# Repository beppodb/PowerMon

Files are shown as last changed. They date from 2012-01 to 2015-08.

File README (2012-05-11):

PowerMon

PowerMon is a device that can be inserted between a computer power supply and the computer's main board to measure power usage at each of the DC power rails supplying the board. The device measures voltage and current on eight DC rails, reporting measurements at a rate of up to 1024 Hz per channel up to 3072 Hz aggregate, and fits in a standard 3.5" hard drive bay.

PowerMon has been used to resolve and highlight variations in power consumption and energy efficiency during individual sub-processes of software applications at the subsystem level.  The parts cost is about $150 each, in small batches. (Assembled cost ~$250, in quantities of 50.)

Related publications:
D. Bedard, M. Lim, R. Fowler, and A. Porterfield, \ldblquote PowerMon: Fine-Grained and Integrated Power Monitoring for Commodity Computer Systems,\rdblquote  Southeastcon, 2010. IEEE, pp start-finish, March 18-21, 2010.

The entire design is licensed under the Renci Open Source License v1.0 (see ./license), meaning, essentially, that you can use it in any otherwise legal project, as long as you provide attribution.

Directory tree:

+-application/    A sample application in C
| +-pm_app.c
+-assembly/       BOM, centroid, drawings, instructions
+-firmware/       Device firmware
| +-bootloader/
| +-system/
|   +-adm1191.c
|   +-adm1191.h
|   +-config.c
|   +-config.h
|   +-powermon.c
|   +-timer2.c
|   +-timer2.h
|   +-usart.c
|   +-usart.h
+-gerber/         Production drawings for printed circuit boards
+-pcb/            Board layout, in Eagle PCB, PDF formats
+-schematic/      Schematic, in Eagle PCB, PDF formats
+-README          This file.
+-license         The RENCI Open Source License v1.0

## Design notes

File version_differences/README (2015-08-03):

This folder demonstrates the differences between the v1.0 and v1.1 designs.
The main difference is the replacement of the crystal used from a 32.5 KHz
crystal to a larger 100 KHz crystal. 

As shown in the two schematic pngs, each crystal is wired up in the same 
fashion to the microcontroller chip, with the newer crystal requiring 
slightly larger capacitor values.

******************************
Part Differences:

v1.0
====
C205,C206 - Capacitors 
---------------------- 
CAP 10pF 50V NP0
Johanson Dielectrics Inc 500R15N100JV4T

X201 - Crystal - 32.768 kHz crystal
-----------------
Crystal 32.7680kHz 12.5pF
Fox Electronics FSXLF327
http://www.digikey.com/product-search/en?keywords=631-1001-1-ND
Size: 0.276" L x 0.060" W (7.00mm x 1.50mm)
Height	0.055" (1.40mm)

v1.1
=====
C205,C206 - Capacitors 
---------------------- 
CAP 18pF 50V NP0
Yageo	CC0805JRNPO9BN180

X1 - Crystal - 100 KHz
-----------------
XTAL 100kHz 12.5pF
Abracon LLC	ABS25-100.000KHZ-T
http://www.digikey.com/product-detail/en/ABS25-100.000KHZ-T/535-10245-1-ND/2218058
Size: 0.315" L x 0.150" W (8.00mm x 3.80mm)
Height: 0.098" (2.50mm)

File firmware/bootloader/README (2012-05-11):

Baremetal bootloader based on AVR Application Note 109. Program using six-pin header and AVR-Dragon, AVR-ISP or similar.

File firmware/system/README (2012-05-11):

PowerMon operational code. Programmed through serial port after the bootloader is installed.

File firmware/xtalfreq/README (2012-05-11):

Crystal frequency monitoring app. Install through serial port (with AVRDUDE) after bootloader.

We had some assembly problems in the v1.0 batch, and this was written to test the crystal. It's not a very good test of crystal frequency, as it's using the ATmega168's internal 8MHz oscillator as the baseline. It's more of a test of crystal operation.

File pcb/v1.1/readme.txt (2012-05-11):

Board layout and schematic are Eagle 5.6.0 format

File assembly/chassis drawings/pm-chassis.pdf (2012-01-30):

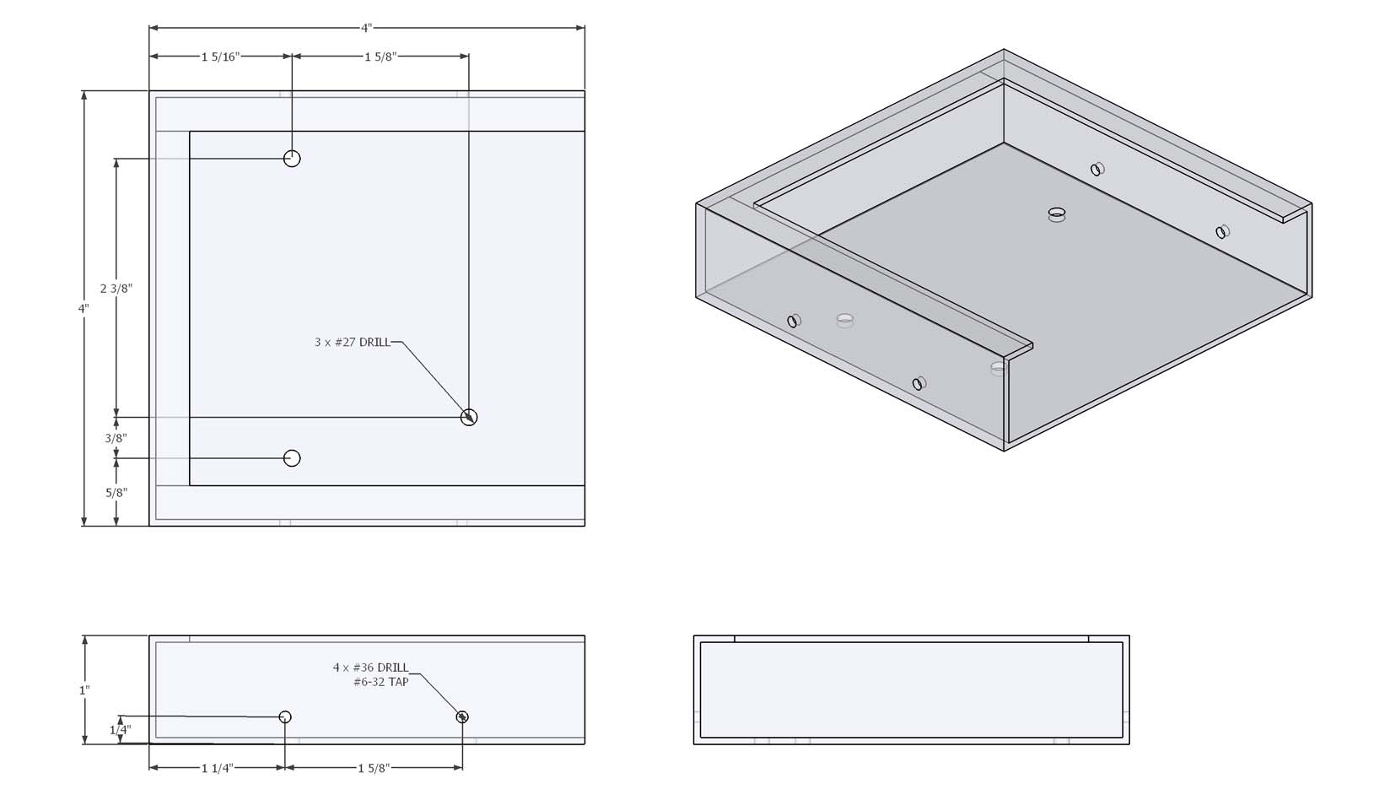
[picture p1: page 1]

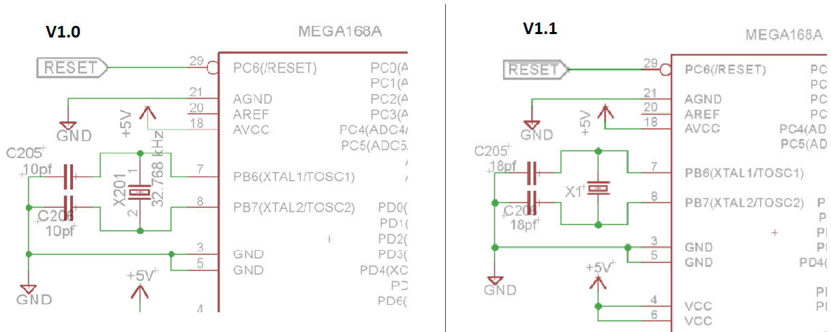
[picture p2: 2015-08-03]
version_differences/X201vs_X1_schematic.png

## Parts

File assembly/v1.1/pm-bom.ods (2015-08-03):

PowerMon2 v1.1 |  | Do not populate items in gray. They are debug/outdated components.
Item # | Qty | Ref Des | Vendor Part Number | Description | Manufacturer | Manufacturer Part Number | Package | Type | Vendor | Pricing 1 unit (CT) | Webpage
1 | 1 | J203 | 609-3218-ND | CON 6 pos .100" header | FCI | 67996-406HLF | connector | thru-hole | Digi-Key | $0.26 | http://www.digikey.com/product-search/en?x=26&y=11&lang=en&site=us&keywords=609-3218-ND
2 | 8 | R303, R305, R311, R317, R322, R323, R403, R422 | 311-0.0ARCT-ND | RES 0 Ohm 1/8W | Yageo | RC0805JR-070RL | 0805 | smt | Digi-Key | $0.10 | http://www.digikey.com/product-detail/en/RC0805JR-070RL/311-0.0ARCT-ND/731163
3 | 8 | R301, R307, R313, R319, R401, R407, R413, R419 | 989-1017-1-ND | RES .005 Ohm 5W 1% | TT Electronics/IRC | OARSXPR005FLF | resistor | smt | Digi-Key | $1.31 | http://www.digikey.com/product-detail/en/OARSXPR005FLF/989-1017-1-ND/2407860
4 | 1 | C203 | 1276-3021-1-ND | CAP 4.7uF 16V Y5V | Samsung | CL21F475ZOFNNNE | 0805 | smt | Digi-Key | $0.27 | http://www.digikey.com/product-detail/en/CL21F475ZOFNNNE/1276-3021-1-ND/3891107
5 | 2 | R201, R202 | 311-10.0KCRCT-ND | RES 10.0K 1/8W 1% | Yageo | RC0805FR-0710KL | 0805 | smt | Digi-Key | $0.10 | http://www.digikey.com/product-detail/en/RC0805FR-0710KL/311-10.0KCRCT-ND/730482
6 | 1 | C201 | 478-1383-1-ND | CAP 10nF 50V X7R | AVX Corporation | 08055C103KAT2A | 0805 | smt | Digi-Key | $0.10 | http://www.digikey.com/product-detail/en/08055C103KAT2A/478-1383-1-ND/564415
7 | 2 | C205, C206 | 311-1102-1-ND | CAP 18pF 50V NP0 | Yageo | CC0805JRNPO9BN180 | 0805 | smt | Digi-Key | $0.10 | http://www.digikey.com/product-detail/en/CC0805JRNPO9BN180/311-1102-1-ND/303012
8 | 1 | X1 - replaces X201 from v1.0 | 535-10245-1-ND | XTAL 100kHz 12.5pF | Abracon LLC | ABS25-100.000KHZ-T | crystal | smt | Digi-Key | $1.23 | http://www.digikey.com/product-detail/en/ABS25-100.000KHZ-T/535-10245-1-ND/2218058
9 | 2 | C202, C204 | 311-1361-1-ND | CAP 100nF 50V Y5V | Yageo | CC0805ZRY5V9BB104 | 0805 | smt | Digi-Key | $0.10 | http://www.digikey.com/product-detail/en/CC0805ZRY5V9BB104/311-1361-1-ND/2103145
10 | 6 | R309, R405, R409, R411, R417, R423 | 311-120KARCT-ND | RES 120k 1/8W 5% | Yageo | RC0805JR-07120KL | 0805 | smt | Digi-Key | $0.10 | http://www.digikey.com/product-detail/en/RC0805JR-07120KL/311-120KARCT-ND/731195
11 | 2 | J101, J102 | WM1829-ND | CON 10 pos R/A Micro-Fit 3.0 | Molex | 430451009 | connector | smt | Digi-Key | $4.19 | http://www.digikey.com/product-detail/en/0430451009/WM1829CT-ND/252542
12 | 2 | J103, J104 | WM1830-ND | CON 12 pos R/A Micro-Fit 3.0 | Molex | 430451209 | connector | smt | Digi-Key | $4.02 | http://www.digikey.com/product-detail/en/0430451209/WM1830CT-ND/252543
13 | 2 | J105, J106 | 538-43045-2009 | CON 20 pos R/A Micro-Fit 3.0 |  |  | connector | smt | Mouser | $6.81 | http://www.mouser.com/ProductDetail/Molex/43045-2009/
14 | 8 | U301, U302, U303, U304, U401, U402, U403, U404 | ADM1191-2ARMz-R7CT-ND | IC power monitor | Analog Devices | ADM1191-2ARMZ-R7 | 10MSOP | fine pitch | Digi-Key | $5.25 | http://www.digikey.com/product-detail/en/ADM1191-2ARMZ-R7/ADM1191-2ARMZ-R7CT-ND/1200225
15 | 1 | U201 | 895-FT232RL | IC usb transceiver |  |  | 28SSOP | smt | Mouser | $4.50 | http://www.mouser.com/ProductDetail/FTDI/FT232RL-REEL/
16 | 1 | L201 | 240-2393-1-ND | ferrite bead Z=120Ohm | Laird-Signal Integrity Products | HI0805O121R-10 | 0805 | smt | Digi-Key | $0.10 | http://www.digikey.com/product-detail/en/HI0805O121R-10/240-2393-1-ND/806753
17 | 1 | U202 | ATMEGA168A-AU-ND | IC microcontroller | Atmel | ATMEGA168A-AU | 32TQFP | smt | Digi-Key | $2.85 | http://www.digikey.com/product-detail/en/ATMEGA168A-AU/ATMEGA168A-AU-ND/2271188
18 | 1 | J201 | A31727CT-ND | CON mini usb r/a type b | TE Connectivity | 1734035-2 | connector | smt | Digi-Key | $1.76 | http://www.digikey.com/product-detail/en/1734035-2/A31727CT-ND/773789
 |  |  |  | BOARD SUMMARY FOR QUOTE
 |  |  |  | Total # of unique parts | 18
 |  |  |  | SMT placements per board | 41
 |  |  |  | Thru-hole placements per board | 1
 |  |  |  | Fine pitch placements per board | 8
 |  |  |  | BGA placements per board | 0
Outdated and Debug Parts
4 |  |  | C203 Original Part (Original Part Specification) | 445-3460-1-ND | CAP 4.7uF 16V Y5V | TDK Corporation | C2012Y5V1C475Z/0.85 | 0805 | smt | Digi-Key |  | TDK Ceramic Capacitor EOLed and replaced by Samsung part above
19 | 1 | J202 | C-GRID-03-70553 | C-GRID-03-70553 (connector) |  |  |  | Do Not Source |  | $0.74 | http://www.mouser.com/ProductDetail/Molex/70553-0001/?qs=tYx%252bZc2nXqqznXDBRnwLig%3D%3D
20 | 18 | R304, R306, R310, R312, R315, R316, R318, R321, R324, R404, R406, R410, R412, R415, R416, R418, R421, R424 | R-US_R0603 | DNS (resistors, presumably 4.7K-15K) |  |  |  | DNS

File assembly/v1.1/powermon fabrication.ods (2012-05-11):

Component | Process | Details | Documents | Vendor | Cost (qty 25) | Cost (qty 50) | Cost (qty 100) | Turnaround
Chassis | Purchase | Hammond Mfg Part Number 1444-9 |  | Digikey www.digikey.com 800-346-6873 | $205.50 | $411.00 | $822.00 | 1 week | need to price
Chassis | Modification | Cut in half. Drill and tap holes. | drawing: pm-chassis.pdf | - |  |  |  | -
PCB | Fabrication | 4 layers, 2-sided solder mask, 2-sided silkscreen, 1oz FR4 | gerber drawings | Sunstone Circuits www.sunstone.com 800-228-8198 | $1,146.75 | $1,222.20 | $1,363.20 | 3 days | x
Components | Purchase | FT232RL and 20-pin connectors | pm-compm.pdf | Mouser www.mouser.com 800-346-6873 | $374.00 | $748.00 | $1,496.00 | 1 week | need to price
Components | Purchase | everything else | pm-compd.pdf | Digikey www.digikey.com 800-346-6873 | $1,781.03 | $3,562.06 | $7,124.12 | 1 week | need to price
PCB | Assembly |  | pm-bom.xlsx pm-centroid gerber drawings | Screaming Circuits www.screamingcircuits.com 866-784-5887 | $939.00 | $1,269.50 | $1,930.00 | 10 days | x
Cable | Assembly |  | pm-cablea.pdf pm-cableb.pdf | TLC Electronics a.williams@tlcelectronics.com www.tlcelectronics.com 561-558-2570 | $1,276.25 | $2,552.50 | $5,105.00 | 3 weeks | asked
PCB | Programming | AVR Dragon probably the best option | firmware and programming scripts | - |  |  |  | -
PCB | Validation |  | script? Procedure? | - |  |  |  | -
Total |  |  |  |  | $5,722.53 | $9,765.26 | $17,840.32
Per unit |  |  |  |  | $228.90 | $195.31 | $178.40

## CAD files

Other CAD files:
assembly/chassis drawings/chassis dim.skp
assembly/chassis drawings/chassis.skp

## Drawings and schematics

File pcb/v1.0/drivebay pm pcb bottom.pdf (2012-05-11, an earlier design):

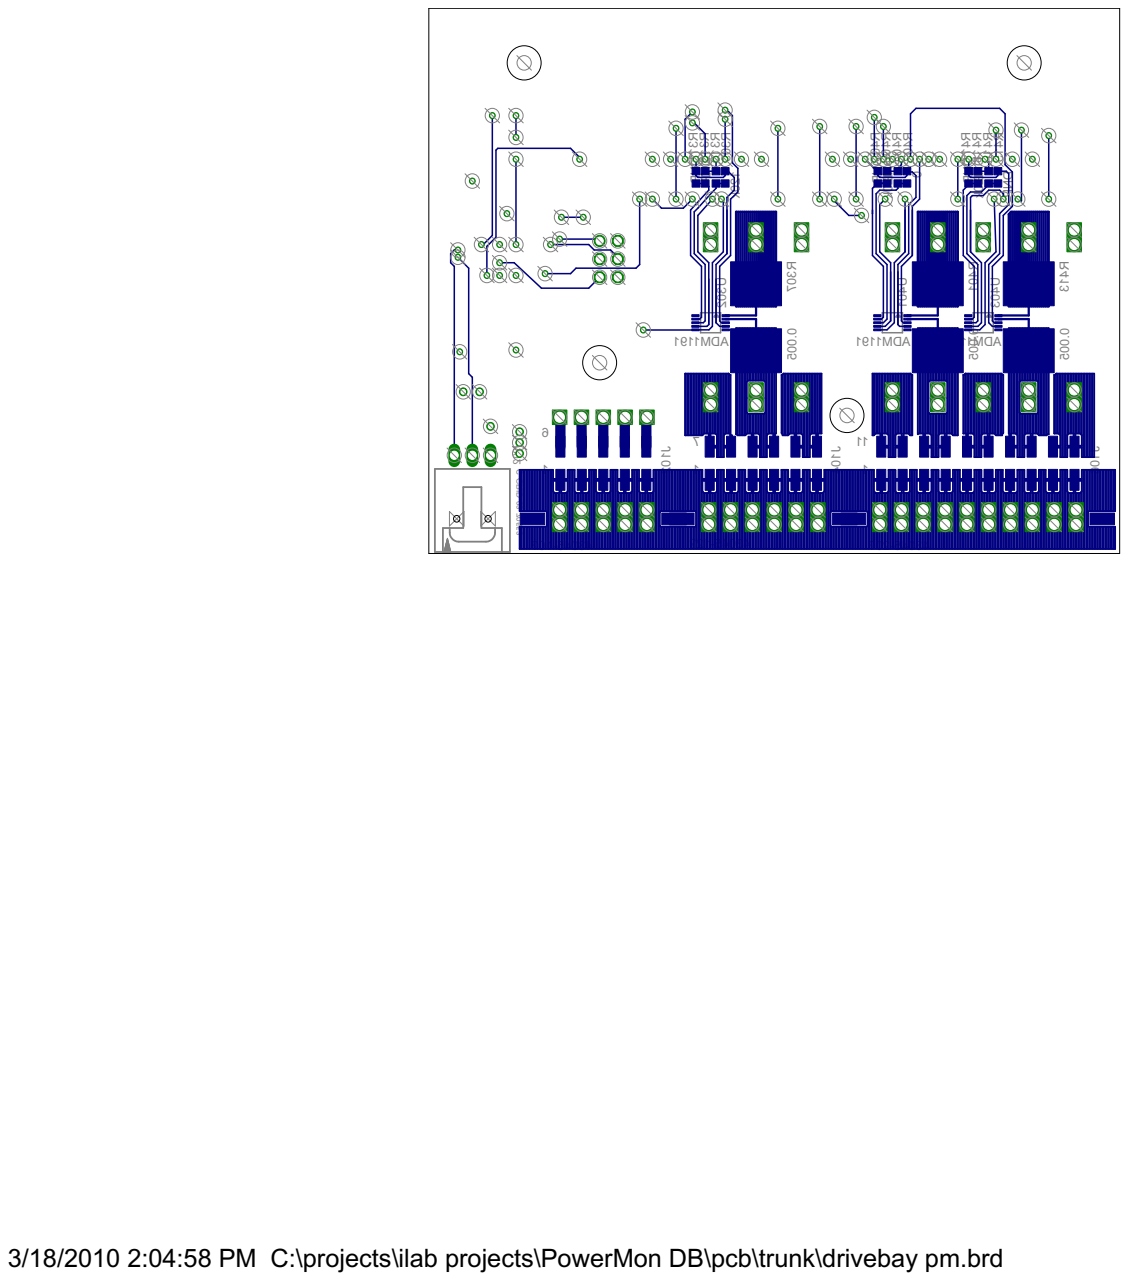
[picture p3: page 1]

3/18/2010 2:04:58 PM C:\projects\ilab projects\PowerMon DB\pcb\trunk\drivebay pm.brd

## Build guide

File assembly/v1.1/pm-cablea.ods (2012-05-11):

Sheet: assembly_1
Position (black) | Position (white) | Wire color
Terminals: Molex 43030-0001 | Terminals: Molex 39-00-0040 | AWG 20, PVC or equivalent insulation
Housing (1): Molex 43025-1200 | Housing: Molex 39-01-2246 | 18" +/- .5"
Housing (2): Molex 43025-1000
1-1 | 3 | black
1-2 | 5 | black
1-3 | 24 | black
1-4 | DNP | black
1-5 | DNP | black
1-6 | DNP | black
1-7 | 10 | yellow
1-8 | 11 | yellow
1-9 | 21,22,23 | red
1-10 | 4,6 | red
1-11 | 2,12 | orange
1-12 | 1,13 | orange
2-1 | 18 | black
2-2 | 19 | black
2-3 | 17 | black
2-4 | 7 | black
2-5 | 15 | black
2-6 | 9 | violet
2-7 | 20 | white
2-8 | 16 | green
2-9 | 8 | gray
2-10 | 14 | blue

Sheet: assembly_2
Position (black) | Position (white) | Wire color
Terminals: Molex 43030-0001 | Terminals: Molex 39-00-0038 | AWG 20, CPVC or equivalent insulation
Housing (1): Molex 43025-1200 | Housing: Molex 39-01-2245
Housing (2): Molex 43025-1000
1-1 | DNP | DNP
1-2 | DNP | DNP
1-3 | DNP | DNP
1-4 | 24 | black
1-5 | 5 | black
1-6 | 3 | black
1-7 | 1,13 | orange
1-8 | 2,12 | orange
1-9 | 4,6 | red
1-10 | 21,22,23 | red
1-11 | 11 | yellow
1-12 | 10 | yellow
2-1 | 15 | black
2-2 | 7 | black
2-3 | 17 | black
2-4 | 19 | black
2-5 | 18 | black
2-6 | 14 | blue
2-7 | 8 | gray
2-8 | 16 | green
2-9 | 20 | white
2-10 | 9 | violet

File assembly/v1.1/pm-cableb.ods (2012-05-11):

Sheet: assembly_1
Qty 20 wires, 18" +/- .5", AWG 20, black PVC or equivalent insulation, terminated with Molex 43030-0001 and Molex 39-00-0040
Qty 1 Molex 43025-2000: DO NOT POPULATE

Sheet: assembly_2
Qty 20 wires, 18" +/- .5", AWG 20, black PVC or equivalent insulation, terminated with Molex 43030-0001 and Molex 39-00-0038
Qty 1 Molex 43025-2000: DO NOT POPULATE

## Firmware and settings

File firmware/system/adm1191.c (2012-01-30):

#include <stdio.h>
#include <inttypes.h>
#include <avr/io.h>
#include <util/twi.h>

#define ADDRESS 0x74

void adm1191_init();
uint8_t adm1191_get(uint8_t *dest, uint8_t remaining_length, uint8_t address);

void adm1191_init() {
	DDRC |= (1 << PC0) | (1 << PC1) | (1 << PC2) | (1 << PC3);
	DDRD |= (1 << PD4) | (1 << PD5) | (1 << PD6) | (1 << PD7);
	DDRC &= ~(1 << PC5 | 1<< PC4);
	
	PORTC |= (1 << PC0) | (1 << PC1) | (1 << PC2) | (1 << PC3); /* enable triggers */
	PORTD |= (1 << PD4) | (1 << PD5) | (1 << PD6) | (1 << PD7);	/* enable triggers */
 	PORTC |= (1 << PC5) | (1 << PC4);  /* enable pullups for scl and sda*/

 	TWSR = 0; /* no prescaler */
	TWBR = 2; /* SCL freq = 8 / 22 = .363 MHz */
}

uint8_t adm1191_put(uint8_t *src, uint8_t remaining_length, uint8_t address) {
	uint8_t transmitted_length = 0;
	uint8_t twst;

	TWCR = (1 << TWINT) | (1 << TWSTA) | (1 << TWEN); /* send start condition */
	while (!(TWCR & (1 << TWINT))); /* wait */

	switch ((twst = TW_STATUS)) 
	{
	case TW_REP_START:
	case TW_START:
/*		printf("  i2c sent start\r\n");*/
		break;
	default:
		return 0;
	}

	TWDR = address | TW_WRITE; /* address + read */
	TWCR = (1 << TWINT) | (1 << TWEN);
	while (!(TWCR & (1 << TWINT)));
/*	printf("  i2c sent %#x\r\n", (address | TW_WRITE));*/
	
	switch ((twst = TW_STATUS)) 
	{
	case TW_MT_SLA_ACK:
/*		printf("  i2c received address ack\r\n");*/
		break;

	default:
/*		printf("  i2c status = %#x\r\n", twst);*/
		TWCR = (1 << TWINT) | (1 << TWSTO) | (1 << TWEN); /* send stop */
		return 0;
	}
	
	while( remaining_length > 0 ) {
		TWDR = src[transmitted_length++];
		remaining_length--;
		TWCR = (1 << TWINT) | (1 << TWEN); /* enable transmission */
		while (!(TWCR & (1 << TWINT))); /* wait */
		switch((twst = TW_STATUS))
		{
		case TW_MT_DATA_ACK:
			break;
		case TW_MT_DATA_NACK:
			return 0;
		default:
			TWCR = (1 << TWINT) | (1 << TWSTO) | (1 << TWEN); /* send stop */			
			return 0;
		}
	}
	return transmitted_length;
}

uint8_t adm1191_get(uint8_t *dest, uint8_t remaining_length, uint8_t address) {
	uint8_t received_length = 0;
	uint8_t twst;
	
	TWCR = (1 << TWINT) | (1 << TWSTA) | (1 << TWEN); /* send start condition */
	while (!(TWCR & (1 << TWINT))); /* wait */

	switch ((twst = TW_STATUS)) 
	{
	case TW_REP_START:
	case TW_START:
/*		printf("  i2c sent start\r\n");*/
		break;
	default:
		return 0;
	}

	TWDR = address | TW_READ; /* address + read */
	TWCR = (1 << TWINT) | (1 << TWEN);
	while (!(TWCR & (1 << TWINT)));
/*	printf("  i2c sent %#x\r\n", (address | TW_READ)); */
	
	switch ((twst = TW_STATUS)) 
	{
	case TW_MR_SLA_ACK:
/*		printf("  i2c received address ack\r\n");*/
		break;

	default:
/*		printf("  i2c status = %#x\r\n", twst);*/
		return 0;
	}
	
	while( remaining_length > 0 ) {
		if( remaining_length == 1) {
			TWCR = (1 << TWINT) | (1 << TWEN); /* send NACK */
		} else {
			TWCR = (1 << TWINT) | (1 << TWEN) | (1 << TWEA); /* send ACK */
		}
		while (!(TWCR & (1 << TWINT)));
		
		switch ((twst = TW_STATUS))
		{
		case TW_MR_DATA_NACK:
		case TW_MR_DATA_ACK:
			remaining_length--;
			*dest++ = TWDR;
			received_length++;
			break;
		
		default:
			TWCR = (1 << TWINT) | (1 << TWSTO) | (1 << TWEN); /* send stop */
			return 0;
		}
	}
	TWCR = (1 << TWINT) | (1 << TWSTO) | (1 << TWEN); /* send stop */
	return received_length;
}

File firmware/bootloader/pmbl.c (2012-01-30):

/*
*
* RENCI
*
* File			: pmbl.c
* Project		: PowerMon Bootloader
* Description	: AVR109-compatible bootloader for PowerMon 2.
* Platform      : ATmega168
* Revision		: 0.1
* Date			: December 29, 2011
*
* License		: RENCI BSD License 1.0
*
* Portions derived from Atmel AVR Application Note 109
*
*/

#include <inttypes.h>
#include <avr/io.h>
#include <avr/boot.h>
#include <avr/eeprom.h>
#include <avr/pgmspace.h>
#include <avr/interrupt.h>
#include <avr/wdt.h>

#define TX_TIMEOUT      10000
#define RX_TIMEOUT      10000
#define US32_SCALER     4

#define APP_MEM_END     14336 // 16384 minus bootloader size (in bytes)
#define PAGE_SIZE       128   // in words
#define BLOCK_SIZE      PAGE_SIZE

// signature for ATMega168
#define	SIGNATURE_BYTE_1 0x1E 
#define	SIGNATURE_BYTE_2 0x94
#define	SIGNATURE_BYTE_3 0x06

#define VERSION_HIGH '0'
#define VERSION_LOW  '1'

#ifndef F_CPU
    #define F_CPU       8000000
#endif

#define US_CYCLES   (F_CPU / 4000000)

// note RX_SAFE will overwrite rx
#define RX_SAFE(rx) {         \
    rx = uart_rx(RX_TIMEOUT); \
    if(rx == -1) {            \
      uart_tx('?');           \
      break;                  \
    }                         \
  }
  
void (*funcptr)(void) = 0x0000; //function pointer points to RESET vector

// prototype declarations
int main(void);
void uart_tx(uint8_t data);
uint8_t uart_hard_rx(uint16_t timeout);
uint8_t uart_soft_rx(uint16_t timeout);
void blockRead(uint16_t size, uint8_t mem, uint16_t *address);
uint8_t blockWrite(uint16_t size, uint8_t mem, uint16_t *address);

void uart_tx(uint8_t data) {    
    UDR0 = data;         
    // wait until data transmitted
    while(!(UCSR0A & (1 << TXC0)));
    UCSR0A |= TXC0; // clear flag
}

uint8_t uart_hard_rx(uint16_t timeout) { // timeout in milliseconds
    uint16_t elapsed = 0;
    while(!(UCSR0A & (1 << RXC0)) && (elapsed < timeout)) {
        if(TIFR0 & (1 << OCF0A)) {
            TCNT0 = 0;
            TIFR0 |= (1 << OCF0A);
            elapsed++;
        }
    }
    if(UCSR0A & (1 << RXC0)) {
        return UDR0;
    } else {
        wdt_enable(WDTO_15MS); //wd on,15ms 
        while(1);
        return 0;
    }
}

uint8_t uart_soft_rx(uint16_t timeout) { // timeout in milliseconds
    uint16_t elapsed = 0;
    while(!(UCSR0A & (1 << RXC0)) && (elapsed < timeout)) {
        if(TIFR0 & (1 << OCF0A)) {
            TCNT0 = 0;
            TIFR0 |= (1 << OCF0A);
            elapsed++;
        }
    }
    if(UCSR0A & (1 << RXC0)) {
        return UDR0;
    } else {
        return 0;
    }
}
          
int main(void) {  
    uint8_t seconds_left;
    uint16_t ms_left;
    uint16_t val;
    uint16_t tmp;
    uint16_t address = 0; //stored as a byte address, but often a word address

    tmp = MCUSR;
    MCUSR = 0;
    wdt_disable();

    cli(); // disable interrupts
    
    
    // init uart
    // set baud rate to 1000000
    UBRR0 = 0; 
    UCSR0A = 1 << U2X0;
    // enable UART rx and tx
    UCSR0B = (1 << RXEN0) | (1 << TXEN0);
    // set 8N1
    UCSR0C = (0 << USBS0) | (1 << UCSZ01) | (1 << UCSZ00);
    DDRD = 1 << PD1;

    // init timer
    OCR0A = 125;
    TCNT0 = 0;
    TIFR0 |= (1 << OCF0A);
    TCCR0B = (1<<CS01) | (1<<CS00);

    //countdown
    seconds_left = 10; 
    ms_left = 0;
    uart_tx('\n');
    uart_tx('\r');
    uart_tx('\n');
    uart_tx('\r');  
    uart_tx((uint8_t)tmp);
    uart_tx('\n');
    uart_tx('\r');  
    while((seconds_left > 0) || (ms_left > 0)) {
        if(uart_soft_rx(1) == 0x1b) { //jump to program space
            break;
        }
        if(ms_left == 0) {
            seconds_left--;
            ms_left = 999;
            uart_tx('p');
            uart_tx('m');
            uart_tx('b');
            uart_tx('l');
            uart_tx(' ');
            uart_tx(seconds_left+'0');
            uart_tx('\n');
            uart_tx('\r');
        } else {
            ms_left--;
        }
    }
    
    if((seconds_left == 0) && (ms_left == 0)) {
        boot_rww_enable_safe();
        funcptr();
    }

    //bootloader loop
    while(1) {
        val=uart_soft_rx(RX_TIMEOUT); // Wait for command character.
        switch(val) {
            case 'a': //Check autoincrement support.
                uart_tx('Y'); //Report "yes".
                break;
            case 'b': //Check block support.
                uart_tx('Y'); //Report "yes".
                uart_tx((BLOCK_SIZE >> 8) & 0xFF);
                uart_tx(BLOCK_SIZE & 0xFF);
                break;                

            case 'A': //Set address.
                address = uart_hard_rx(RX_TIMEOUT);
                address <<= 8;
                address |= uart_hard_rx(RX_TIMEOUT);
                uart_tx('\r'); // send OK
                break;

            case 'e': //Erase chip.
                for(address = 0; address < APP_MEM_END; address += PAGE_SIZE) {
                    boot_page_erase_safe(address);
                }
                uart_tx('\r'); // send OK
                break;

            case 'R': //Read program memory.
                boot_rww_enable_safe();
                uart_tx(pgm_read_byte((address << 1)+1));
                uart_tx(pgm_read_byte((address << 1)+0));
                address++;
                break;
            case 'c': //Write low byte to program memory. (Always goes first.)
                tmp = uart_hard_rx(RX_TIMEOUT);
                uart_tx('\r'); //send OK.                
                break;
            case 'C': //Write high byte to program memory.
                tmp |= (uart_hard_rx(RX_TIMEOUT) << 8);
                boot_page_fill_safe(address << 1, tmp);
                address++;
                uart_tx('\r');
                break;
            case 'm': //Write page.
                if(address >= (APP_MEM_END >> 1)) { 
                    uart_tx('?');                
                } else {
                    boot_page_write_safe(address << 1);
                    uart_tx('\r'); //Send ok.
                }
                break;

            case 'd': //Read EEPROM
                uart_tx(eeprom_read_byte((uint8_t *)address));
                address++;
                break;
            case 'D': //Write EEPROM.                
                tmp = uart_hard_rx(RX_TIMEOUT);
                boot_spm_busy_wait();                
//                EEARL = address;
//                EEARH = (address >> 8);
//                EECR |= (1<<EEMPE);
//                EECR |= (1<<EEPE);
//                while(EECR & (1<<EEPE));
//                address++;
                eeprom_write_byte((uint8_t *)address, (uint8_t)tmp);
                eeprom_busy_wait();
                address++;
                uart_tx('\r'); //Send OK.
                break;

            case 'g': //Start block read.
                // Get block size;
                tmp = uart_hard_rx(RX_TIMEOUT);
                tmp <<= 8;
                tmp |= uart_hard_rx(RX_TIMEOUT);
                val = uart_hard_rx(RX_TIMEOUT);
                blockRead(tmp,val,&address); // Do block read.
                break;
            case 'B': //Start block write.
                // Get block size;
                tmp = uart_hard_rx(RX_TIMEOUT);
                tmp <<= 8;
                tmp |= uart_hard_rx(RX_TIMEOUT);
                val = uart_hard_rx(RX_TIMEOUT);
                uart_tx(blockWrite(tmp,val,&address)); // Do block load, return result.
                break;

            case 'F': //Read low fuse bits.
                boot_spm_busy_wait();
                tmp = boot_lock_fuse_bits_get(GET_LOW_FUSE_BITS);
                uart_tx((uint8_t)tmp);
                break;
            case 'N': //Read high fuse bits.
                boot_spm_busy_wait();
                tmp = boot_lock_fuse_bits_get(GET_HIGH_FUSE_BITS);
                uart_tx((uint8_t)tmp);
                break;
            case 'Q': //Read extended fuse bits.
                boot_spm_busy_wait();
                tmp = boot_lock_fuse_bits_get(GET_EXTENDED_FUSE_BITS);
                uart_tx((uint8_t)tmp);
                break;
            case 'r': //Read lock bits.
                boot_spm_busy_wait();
                tmp = boot_lock_fuse_bits_get(GET_LOCK_BITS);
                uart_tx((uint8_t)tmp);
                break;
            case 'l': //Set lock bits.
                tmp = uart_hard_rx(RX_TIMEOUT);
                boot_lock_bits_set_safe(~((uint8_t)tmp));
                uart_tx('\r'); // Send OK.
                break;

            case 'E': //Exit bootloader.
                uart_tx('\r');
                boot_rww_enable_safe();
                funcptr(); // XXX
                break;

            case 'p'://Get programmer type.
                uart_tx('S'); //'SERIAL'
                break;
            case 's': //Get signature bytes
                uart_tx(SIGNATURE_BYTE_3);
                uart_tx(SIGNATURE_BYTE_2);
                uart_tx(SIGNATURE_BYTE_1);
                break;
            case 't'://Get supported device codes.
                uart_tx(0);
                break;
            case 'S': //Return programmer ID
                uart_tx('P');
                uart_tx('M');
                uart_tx('B');
                uart_tx('L');
                uart_tx(' ');
                uart_tx(' ');
                uart_tx(' ');
                break;
            case 'V':
                uart_tx(VERSION_HIGH);
                uart_tx(VERSION_LOW);
                break;

            case 'L': //Leave programming mode.
            case 'P': //Enter programming mode.
                uart_tx('\r'); //Send OK.
                break;

            case 'x': //set LED
            case 'y': //clear LED
            case 'T': //Set device type.
                uart_soft_rx(RX_TIMEOUT); //ignore
                uart_tx('\r');//Send OK.
                break;

            case 0x1b: //sync
            case 0:   //default
                break;
           
            default: //anything else
                uart_tx('?');
        } // switch        
      } // while    
} //main

void blockRead(uint16_t size, uint8_t mem, uint16_t *address) {    
    if(mem=='E') { //EEPROM    
        while(size > 0) {
            uart_tx(eeprom_read_byte((uint8_t *)(*address)));
            (*address)++;
            size--;     
        }        
    } else if(mem=='F') { //Flash
        while(size > 0) {
            boot_rww_enable_safe();
            uart_tx(pgm_read_byte((*address) << 1));
            uart_tx(pgm_read_byte(((*address) << 1)+1));
            (*address)++;
            size -= 2;
        }
    } else {
        uart_tx('?');
    }
}

// size in bytes
// mem = EEPROM or Flash
uint8_t blockWrite(uint16_t size, uint8_t mem, uint16_t *address) {
    uint8_t buffer[BLOCK_SIZE];
    uint16_t tmp;
    uint16_t data;
    uint16_t temp_address;
//    uint16_t rx;
	
    // EEPROM 
    if(mem=='E') {        
        // Fill buffer.
        for(tmp=0;tmp<size;tmp++) {
            data = uart_hard_rx(RX_TIMEOUT);
//            if(rx == -1) {
//                return '?';
//            }
            buffer[tmp] = (uint8_t)data;
        }
        // Then program.
        boot_spm_busy_wait();
    	for(tmp=0;tmp<size;tmp++) {
            eeprom_write_byte((uint8_t *)(*address), buffer[tmp]);
            eeprom_busy_wait();
            (*address)++;
        }
        return '\r'; //Return OK
    //Flash
    } else if(mem=='F') {
        (*address) <<= 1;
        temp_address = (*address);
        while(size) {
            data = uart_hard_rx(RX_TIMEOUT);
//            if(rx == -1) {
//                return '?';
//            }
//            data = (rx & 0xFF);
//            rx = uart_rx(RX_TIMEOUT);
//            if(rx == -1) {
//                return '?';
//            }
            tmp = uart_hard_rx(RX_TIMEOUT);
            tmp <<= 8;
            data |= tmp;            
            boot_page_fill_safe(*address, data);
            (*address) += 2;
            size -= 2;
        }
        boot_page_write_safe(temp_address);
//        boot_rww_enable_safe(); //I don't think this is necessary.
        (*address) >>= 1;
        return '\r'; // Return OK
    } else { //invalid memory type
        return '?';
    }
}

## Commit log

2012-01-30 Initial checkin of majority of design tree
    [pm-bom.xlsx, pm-cablea.xlsx, pm-cableb.xlsx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]
2012-05-11 Reorganized directories in anticipation of v1.1. Added xtalfreq and todos.
    [drivebay pm.brd, drivebay pm.sch, pm-bom.ods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]
2012-05-11 adding chassis drawings in Google Sketchup format
    [chassis dim.skp, chassis.skp]
2015-07-31 Updated Centroid
    Added J203 Through Hole Part location and updated X1.
    [pm-centroid.csv]
2015-07-31 Updated BOM
    Added weblinks for components and a replacement component for C203.
    [pm-bom.ods]
2015-07-31 Added a new folder to call out differences between v1.0 and v1.1
    Shows the difference between the crystals that are used.
    [pm-centroid_v10_vs_v11.csv]
2015-07-31 Updated Crystal Schematic
2015-07-31 Remove duplicate schematic files.
